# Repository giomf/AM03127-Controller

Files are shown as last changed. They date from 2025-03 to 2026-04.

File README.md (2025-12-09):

# AM03127 LED Panel Controller

This project provides a controller for AM03127 LED panels using an ESP32-C3 microcontroller. It communicates with the panel via RS232 and exposes a REST API through an HTTP server, along with a web interface for easy control.

## Features

- Control AM03127 LED panels via RS232 communication
- Display text with various animations and effects
- Create and manage schedules for automated content display
- Set and display the panel's internal clock
- RESTful API for programmatic control
- Web interface for easy management and OTA updates

## Hardware Requirements

- ESP32-C3 microcontroller
- AM03127 LED panel
- RS232 interface between ESP32-C3 and LED panel

## PCB Design

A custom PCB has been designed for this project. All PCB-related files, including schematics, board layouts, and manufacturing files, can be found in the [PCB](PCB/) folder.

## Software Architecture

The project is built with Rust and uses the following components:

- **Embassy**: Async runtime for embedded systems
- **ESP-HAL**: Hardware abstraction layer for ESP32 devices
- **PicoServe**: Lightweight HTTP server for embedded systems
- **Heapless**: Collections that don't require dynamic memory allocation

## API Documentation

The REST API documentation is available as [OpenAPI Specification](docs/openapi.yaml)

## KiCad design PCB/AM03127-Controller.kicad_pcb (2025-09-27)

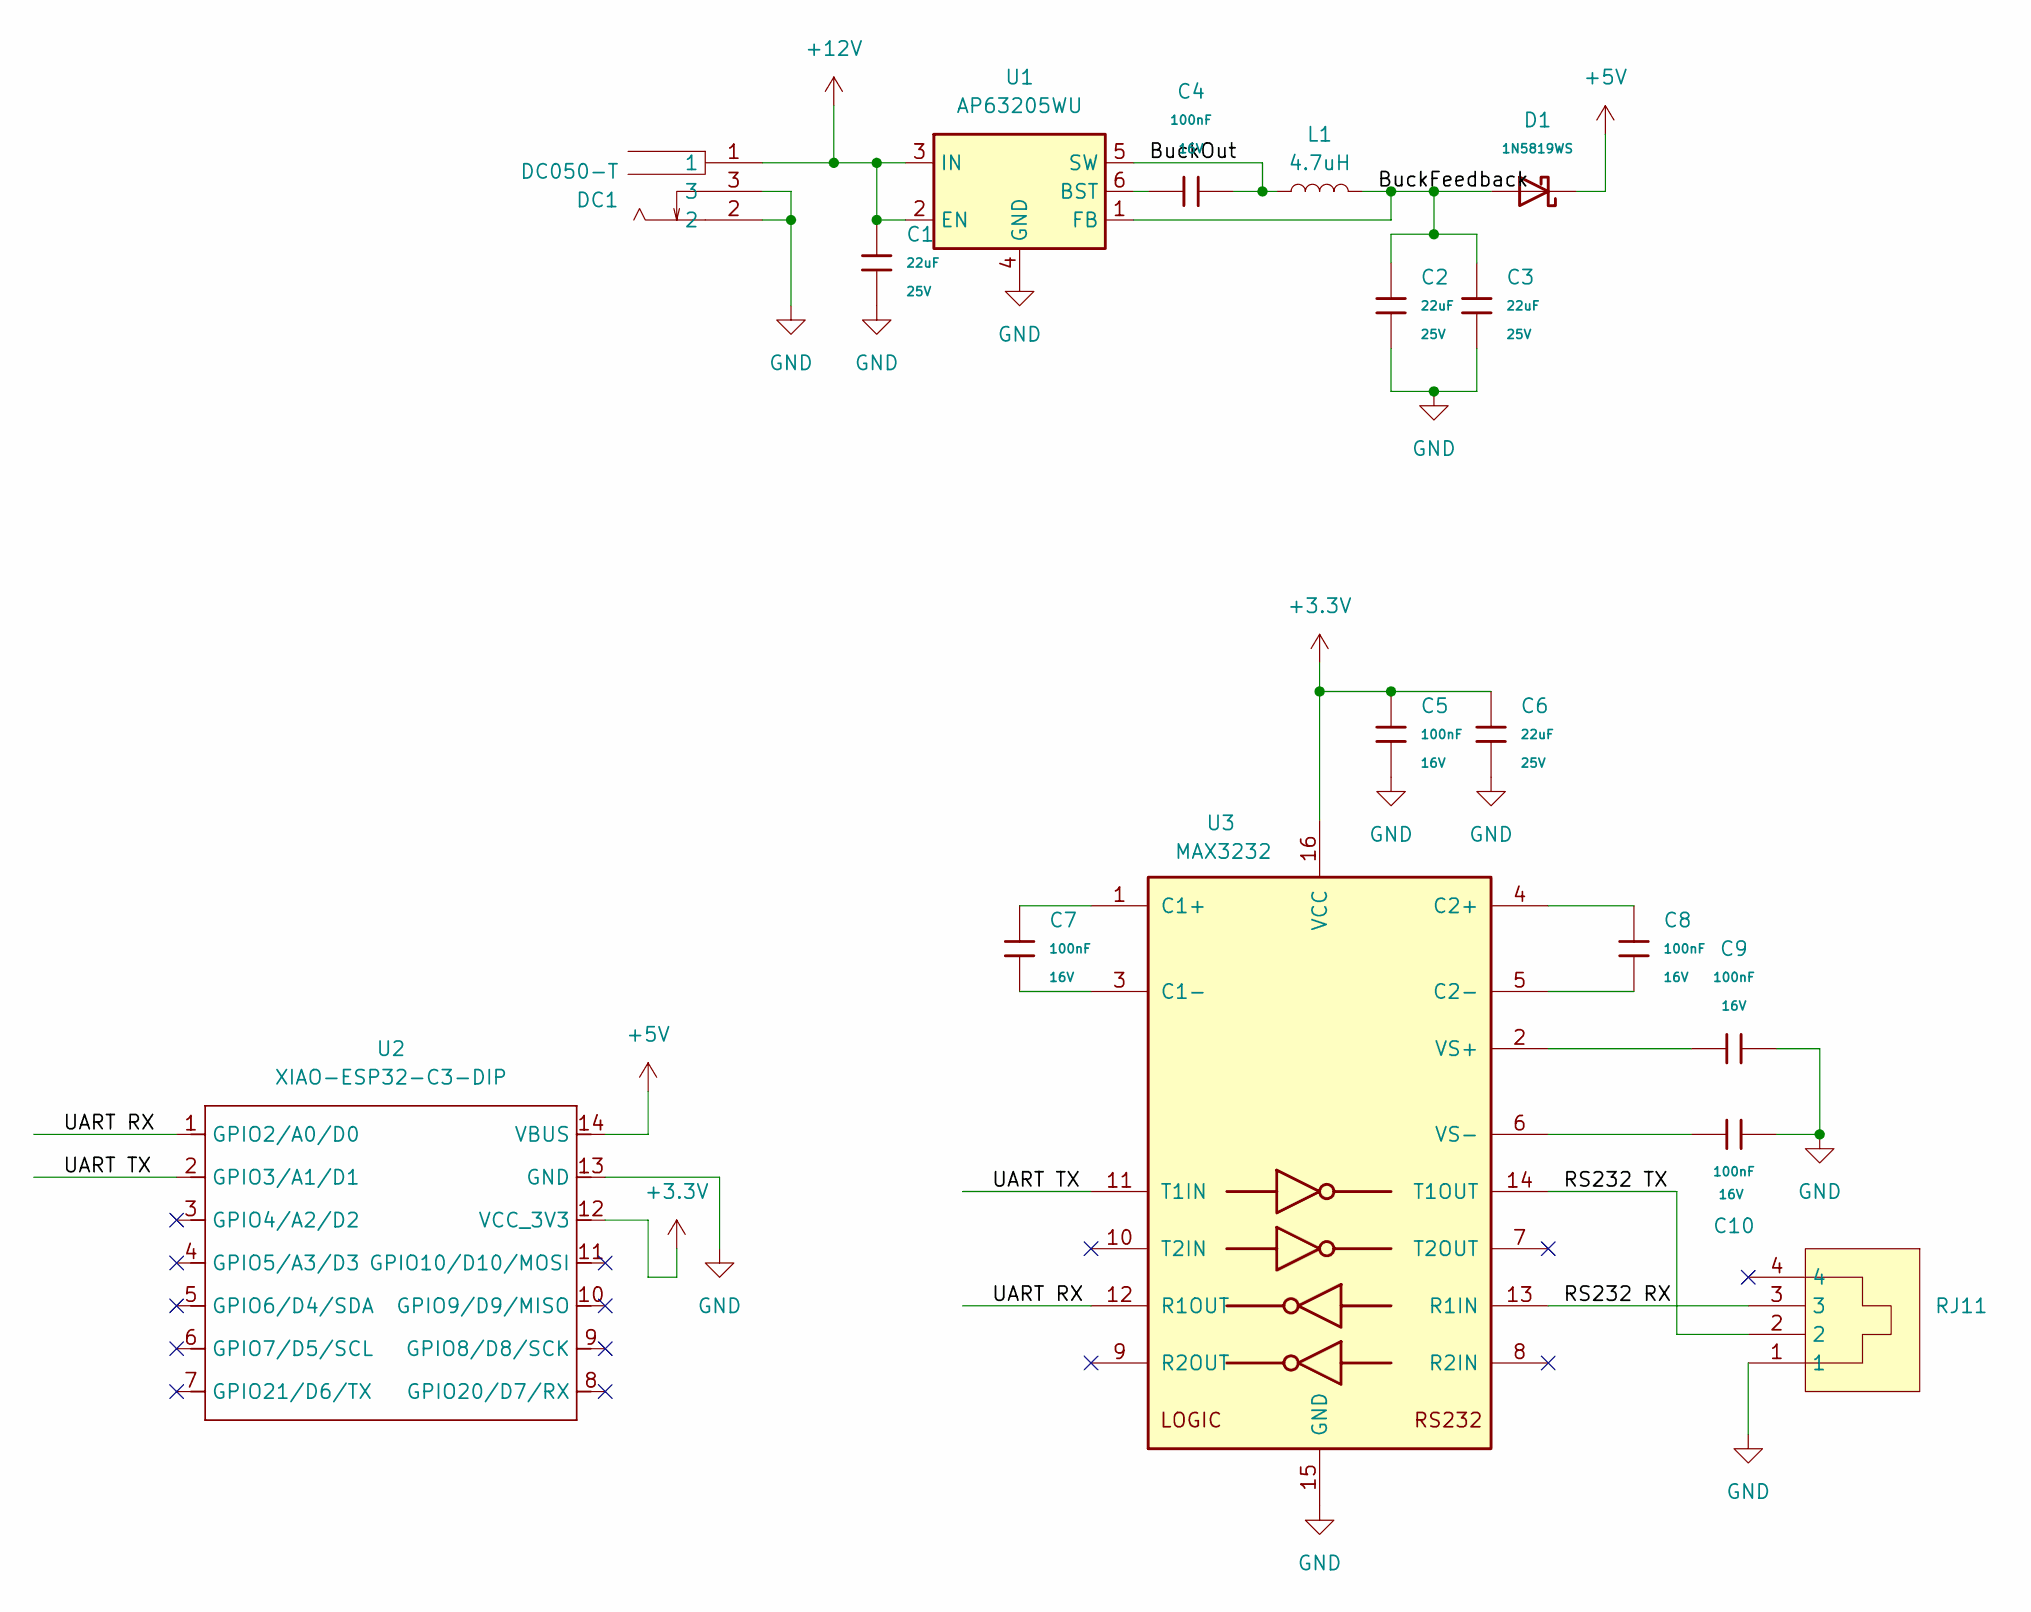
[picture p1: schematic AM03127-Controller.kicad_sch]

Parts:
C1, C2, C3, C6: 22uF; C_1206; Voltage Rated 25V; Tolerance ±10%; Part CL31A226KAHNNNE; LCSC C12891
C4, C5, C7, C8, C9, C10: 100nF; C_0402; Voltage Rated 16V; Tolerance ±10%; Part CL05B104KO5NNNC; LCSC C1525
D1: 1N5819WS; D_SOD-323; Forward Voltage (Vf@If) 600mV@1A; Reverse Voltage (Vr) 40V; Part 1N5819WS; LCSC C191023
DC1: DC050-T; DC-IN_DC050-T; LCSC Part C431534
L1: 4.7uH; L_1008_2520Metric
RJ11: PCB-6P4C-90_C189746; RJ11-TH_PCB-6P4C-90_C189746; LCSC Part C189746
U1: AP63205WU; TSOT-23-6
U2: XIAO-ESP32-C3-DIP; XIAO-ESP32C3-DIP
U3: MAX3232; SOIC-16_3.9x9.9mm_P1.27mm

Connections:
+3.3V: C5.1, C6.1, U2.12 (VCC_3V3), U3.16 (VCC)
+5V: D1.1, U2.14 (VBUS)
+12V: C1.1, DC1.1, U1.2 (EN), U1.3 (IN)
/BuckFeedback: C2.1, C3.1, D1.2, L1.2, U1.1 (FB)
/BuckOut: C4.2, L1.1, U1.5 (SW)
/RS232 RX: RJ11.3, U3.13 (R1IN)
/RS232 TX: RJ11.2, U3.14 (T1OUT)
/UART RX: U2.1 (GPIO2/A0/D0), U3.12 (R1OUT)
/UART TX: U2.2 (GPIO3/A1/D1), U3.11 (T1IN)
GND: C1.2, C2.2, C3.2, C5.2, C6.2, C9.2, C10.2, DC1.2, DC1.3, RJ11.1, U1.4 (GND), U2.13 (GND), U3.15 (GND)
unnamed: C4.1, U1.6 (BST)
unnamed: C7.1, U3.1 (C1+)
unnamed: C7.2, U3.3 (C1-)
unnamed: C8.1, U3.4 (C2+)
unnamed: C8.2, U3.5 (C2-)
unnamed: C9.1, U3.2 (VS+)
unnamed: C10.1, U3.6 (VS-)

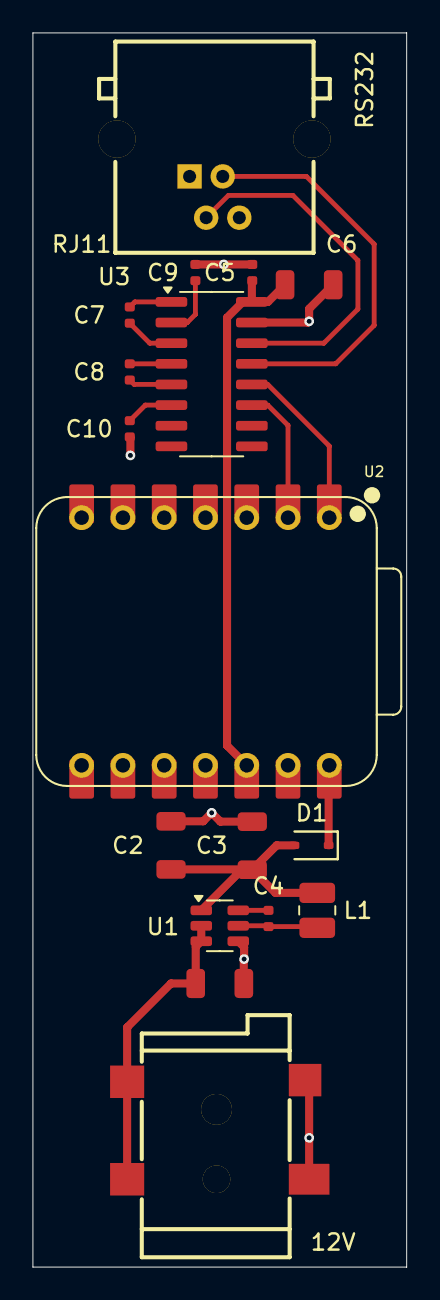
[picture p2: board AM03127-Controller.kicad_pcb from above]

Board: 2 copper layers, 23.0 x 76.0 mm, 17 parts (0 on the bottom side), 17 nets.

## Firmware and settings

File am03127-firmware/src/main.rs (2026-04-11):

#![recursion_limit = "256"]
#![no_std]
#![no_main]
#![feature(impl_trait_in_assoc_type)]
#[deny(clippy::mem_forget)]
#[cfg(feature = "sntp")]
mod clock;
mod error;
mod panel;
mod server;
mod storage;
mod uart;

use embassy_executor::Spawner;
use embassy_net::{Runner, Stack as NetworkStack, StackResources};
use embassy_sync::{blocking_mutex::raw::CriticalSectionRawMutex, mutex::Mutex};
use embassy_time::{Duration, Timer};
use esp_alloc as _;
use esp_backtrace as _;
use esp_bootloader_esp_idf::{esp_app_desc, ota_updater::OtaUpdater};
use esp_hal::{
    clock::CpuClock, interrupt::software::SoftwareInterruptControl, peripherals::WIFI, ram,
    rng::Rng, timer::timg::TimerGroup,
};
use esp_radio::{
    Controller, init,
    wifi::{ClientConfig, ModeConfig, WifiController, WifiDevice, WifiEvent, WifiStaState},
};
use esp_storage::FlashStorage;
use panel::Panel;
use picoserve::{AppRouter, AppWithStateBuilder, Config as ServerConfig, Router, make_static};
use server::{AppState, ServerProperties, web_task};
use uart::Uart;

#[cfg(feature = "sntp")]
use crate::clock::timing_task;

const WEB_TASK_POOL_SIZE: usize = 2;
// Webtask poolsize + sntp socket + one extra
#[cfg(feature = "sntp")]
const STACK_RESSOURCE_SIZE: usize = WEB_TASK_POOL_SIZE + 1 + 1;
// Webtask poolsize + one extra
#[cfg(not(feature = "sntp"))]
const STACK_RESSOURCE_SIZE: usize = WEB_TASK_POOL_SIZE + 1;
const SSID: &str = env!("WIFI_SSID");
const PASSWORD: &str = env!("WIFI_PASS");
const PANEL_INIT_DELAY_SECS: u64 = 10;
const WIFI_DELAY_SECS: u64 = 5;

pub type SharedUart = &'static Mutex<CriticalSectionRawMutex, Uart<'static>>;
pub type SharedStorage = &'static Mutex<CriticalSectionRawMutex, FlashStorage<'static>>;

esp_app_desc!(
    env!("BUILD_VERSION"), // version
    "AM03127-Controller",  // project name
    env!("BUILD_TIME"),    // build time
    env!("BUILD_DATE"),    // build date
    "5.2",                 // ESP-IDF version
    64 * 1024,             // MMU page size
    0,                     // min eFuse block revision
    u16::MAX               // max eFuse block revision
);

#[esp_rtos::main]
async fn main(spawner: Spawner) {
    esp_println::logger::init_logger_from_env();
    let esp_config = esp_hal::Config::default().with_cpu_clock(CpuClock::max());
    let peripherals = esp_hal::init(esp_config);

    // 100 KB Heap
    esp_alloc::heap_allocator!(#[ram(reclaimed)] size: 64 * 1024);
    esp_alloc::heap_allocator!(size: 36 * 1024);

    let timg0 = TimerGroup::new(peripherals.TIMG0);
    let shared_uart = make_static!(
        Mutex<CriticalSectionRawMutex, Uart>, Mutex::new(Uart::new(peripherals.UART1, peripherals.GPIO3, peripherals.GPIO2))
    );
    let shared_storage = make_static!(Mutex<CriticalSectionRawMutex, FlashStorage>, Mutex::new(FlashStorage::new(peripherals.FLASH)));
    let panel = make_static!(Panel, Panel::new(shared_uart, shared_storage));

    let mut ota_buffer = [0u8; esp_bootloader_esp_idf::partitions::PARTITION_TABLE_MAX_LEN];
    let (selected_partition, booted_partition) = {
        let flash = &mut *shared_storage.lock().await;
        let mut pt_buffer = [0u8; esp_bootloader_esp_idf::partitions::PARTITION_TABLE_MAX_LEN];
        let pt = esp_bootloader_esp_idf::partitions::read_partition_table(flash, &mut pt_buffer)
            .unwrap();
        let booted = pt
            .booted_partition()
            .ok()
            .flatten()
            .map(|p| p.partition_type());
        let mut ota = OtaUpdater::new(flash, &mut ota_buffer).unwrap();
        let selected = ota.selected_partition().unwrap();
        (selected, booted)
    };

    log::info!("==========================================");
    log::info!("\tAM03127-Controller");
    log::info!("\tVersion:\t\t{}", env!("BUILD_VERSION"));
    log::info!(
        "\tBuilt:\t\t\t{} {}",
        env!("BUILD_DATE"),
        env!("BUILD_TIME")
    );
    match booted_partition {
        Some(p) => log::info!("\tBooted partition:\t{:?}", p),
        None => log::info!("\tBooted partition:\tUnknown"),
    }
    log::info!("\tSelected partition:\t{:?}", selected_partition);
    log::info!("==========================================");

    #[cfg(target_arch = "riscv32")]
    let sw_int = SoftwareInterruptControl::new(peripherals.SW_INTERRUPT);
    esp_rtos::start(
        timg0.timer0,
        #[cfg(target_arch = "riscv32")]
        sw_int.software_interrupt0,
    );

    let (wifi_controller, wifi_interface) = init_wifi(peripherals.WIFI);
    let (network_stack, network_runner) = init_network(wifi_interface);
    let (server_app, server_config) = init_server();

    spawner.must_spawn(wifi_task(wifi_controller, network_stack));
    spawner.must_spawn(network_task(network_runner));
    spawner.must_spawn(panel_init_task(panel));
    #[cfg(feature = "sntp")]
    spawner.must_spawn(timing_task(network_stack, panel));

    for id in 0..WEB_TASK_POOL_SIZE {
        spawner.must_spawn(web_task(
            id,
            network_stack,
            server_app,
            server_config,
            AppState {
                panel: panel,
                storage: shared_storage,
            },
        ));
    }
}

fn init_wifi(wifi: WIFI<'static>) -> (WifiController<'static>, WifiDevice<'static>) {
    let esp_radio_ctrl = &*make_static!(Controller<'static>, init().unwrap());
    let (controller, interfaces) =
        esp_radio::wifi::new(&esp_radio_ctrl, wifi, Default::default()).unwrap();
    let device = interfaces.sta;

    return (controller, device);
}

fn init_network(
    wifi_device: WifiDevice<'static>,
) -> (NetworkStack<'static>, Runner<'static, WifiDevice<'static>>) {
    let rng = Rng::new();
    let config = embassy_net::Config::dhcpv4(Default::default());
    let seed = (rng.random() as u64) << 32 | rng.random() as u64;

    // Init network stack
    embassy_net::new(
        wifi_device,
        config,
        make_static!(StackResources<STACK_RESSOURCE_SIZE>, StackResources::new()),
        seed,
    )
}

fn init_server() -> (
    &'static mut Router<<ServerProperties as AppWithStateBuilder>::PathRouter, AppState>,
    &'static mut ServerConfig,
) {
    let server_app = make_static!(AppRouter<ServerProperties>, ServerProperties.build_app());
    let server_config = make_static!(
        ServerConfig,
        ServerConfig::new(picoserve::Timeouts {
            persistent_start_read_request: Duration::from_secs(5),
            start_read_request: Duration::from_secs(5),
            read_request: Duration::from_secs(60),
            write: Duration::from_secs(2),
        })
        .keep_connection_alive()
    );

    (server_app, server_config)
}

#[embassy_executor::task]
async fn wifi_task(
    mut wifi_controller: WifiController<'static>,
    network_stack: NetworkStack<'static>,
) {
    const LOGGER_NAME: &str = "WIFI";
    log::info!("{LOGGER_NAME}: Start wifi connection task");

    loop {
        if matches!(esp_radio::wifi::sta_state(), WifiStaState::Connected) {
            // wait until we're no longer connected
            wifi_controller
                .wait_for_event(WifiEvent::StaDisconnected)
                .await;
            log::info!("{LOGGER_NAME}: Wifi disconnected");
            Timer::after(Duration::from_secs(WIFI_DELAY_SECS)).await
        }
        if !matches!(wifi_controller.is_started(), Ok(true)) {
            let client_config = ModeConfig::Client(
                ClientConfig::default()
                    .with_ssid(SSID.try_into().unwrap())
                    .with_password(PASSWORD.try_into().unwrap()),
            );
            wifi_controller.set_config(&client_config).unwrap();
            log::info!("{LOGGER_NAME}: Starting wifi");
            wifi_controller.start_async().await.unwrap();
            log::info!("{LOGGER_NAME}: Wifi started");
        }

        match wifi_controller.connect_async().await {
            Ok(_) => {
                log::info!("{LOGGER_NAME}: Wifi connected to {SSID}");
                network_stack.wait_link_up().await;
                log::info!("{LOGGER_NAME}: Getting DHCP IP address");
                network_stack.wait_config_up().await;

                match network_stack.config_v4() {
                    Some(config) => {
                        log::info!("{LOGGER_NAME}: Received DHCP IP address {}", config.address)
                    }
                    None => log::error!("{LOGGER_NAME}: Failed to receive DHCP IP address"),
                }
            }
            Err(e) => {
                log::info!(
                    "{LOGGER_NAME}: Failed to connect to wifi \"{SSID}\": {:?}",
                    e
                );
                Timer::after(Duration::from_secs(WIFI_DELAY_SECS)).await
            }
        }
    }
}

#[embassy_executor::task]
async fn network_task(mut runner: Runner<'static, WifiDevice<'static>>) -> ! {
    const LOGGER_NAME: &str = "Network";
    log::info!("{LOGGER_NAME}: Start network task");
    runner.run().await
}

#[embassy_executor::task]
async fn panel_init_task(panel: &'static Panel) {
    Timer::after(Duration::from_secs(PANEL_INIT_DELAY_SECS)).await;

    match panel.init().await {
        Ok(_) => log::info!("Panel initialized"),
        Err(e) => log::error!("Failed to initialize panel. {e}"),
    }
}

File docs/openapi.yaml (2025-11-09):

openapi: 3.0.3
info:
  title: LED Panel Control API
  description: API for controlling AM03127 LED panels
  version: 1.0.0
servers:
  - url: http://localhost:80
    description: Local development server
paths:
  /page/{pageId}:
    parameters:
      - name: pageId
        in: path
        required: true
        schema:
          type: string
          pattern: '^[A-Z]$'
        description: Single uppercase letter (A-Z) identifying the page
    get:
      summary: Get a specific page
      description: Retrieves the content and settings of a specific page by ID
      responses:
        '200':
          description: Page found and returned
          content:
            application/json:
              schema:
                $ref: '#/components/schemas/Page'
        '400':
          description: Invalid page ID
          content:
            text/plain:
              schema:
                type: string
        '404':
          description: Page not found
          content:
            text/plain:
              schema:
                type: string
        '500':
          description: Internal server error
          content:
            text/plain:
              schema:
                type: string
    post:
      summary: Create or update a page
      description: Creates a new page or updates an existing page with the specified ID
      requestBody:
        required: true
        content:
          application/json:
            schema:
              $ref: '#/components/schemas/Page'
      responses:
        '200':
          description: Page created or updated successfully
        '400':
          description: Invalid page ID or request body
          content:
            text/plain:
              schema:
                type: string
        '500':
          description: Internal server error
          content:
            text/plain:
              schema:
                type: string
    delete:
      summary: Delete a page
      description: Deletes a page with the specified ID
      responses:
        '200':
          description: Page deleted successfully
        '400':
          description: Invalid page ID
          content:
            text/plain:
              schema:
                type: string
        '500':
          description: Internal server error
          content:
            text/plain:
              schema:
                type: string
  /pages:
    get:
      summary: Get all pages
      description: Retrieves all stored pages
      responses:
        '200':
          description: List of pages
          content:
            application/json:
              schema:
                type: array
                items:
                  $ref: '#/components/schemas/Page'
        '500':
          description: Internal server error
          content:
            text/plain:
              schema:
                type: string
    post:
      summary: Create or update multiple pages
      description: Creates or updates multiple pages at once
      requestBody:
        required: true
        content:
          application/json:
            schema:
              type: array
              items:
                $ref: '#/components/schemas/Page'
      responses:
        '200':
          description: Pages created or updated successfully
        '400':
          description: Invalid request body
          content:
            text/plain:
              schema:
                type: string
        '500':
          description: Internal server error
          content:
            text/plain:
              schema:
                type: string
  /schedule/{scheduleId}:
    parameters:
      - name: scheduleId
        in: path
        required: true
        schema:
          type: string
          pattern: '^[A-E]$'
        description: Single uppercase letter (A-E) identifying the schedule
    get:
      summary: Get a specific schedule
      description: Retrieves a specific schedule by ID
      responses:
        '200':
          description: Schedule found and returned
          content:
            application/json:
              schema:
                $ref: '#/components/schemas/Schedule'
        '400':
          description: Invalid schedule ID
          content:
            text/plain:
              schema:
                type: string
        '404':
          description: Schedule not found
          content:
            text/plain:
              schema:
                type: string
        '500':
          description: Internal server error
          content:
            text/plain:
              schema:
                type: string
    post:
      summary: Create or update a schedule
      description: Creates a new schedule or updates an existing schedule with the specified ID
      requestBody:
        required: true
        content:
          application/json:
            schema:
              $ref: '#/components/schemas/Schedule'
      responses:
        '200':
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

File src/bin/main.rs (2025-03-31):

#![no_std]
#![no_main]

use embassy_executor::Spawner;
use embassy_net::{Runner,  StackResources};
use embassy_time::{Duration, Timer};
use esp_alloc as _;
use esp_hal::timer::systimer::SystemTimer;
use esp_hal::{clock::CpuClock, rng::Rng, timer::timg::TimerGroup};
use esp_backtrace as _;
use esp_println::println;
use esp_wifi::{
    EspWifiController, init,
    wifi::{ClientConfiguration, Configuration, WifiController, WifiDevice, WifiEvent, WifiState},
};

// When you are okay with using a nightly compiler it's better to use https://docs.rs/static_cell/2.1.0/static_cell/macro.make_static.html
macro_rules! mk_static {
    ($t:ty,$val:expr) => {{
        static STATIC_CELL: static_cell::StaticCell<$t> = static_cell::StaticCell::new();
        #[deny(unused_attributes)]
        let x = STATIC_CELL.uninit().write(($val));
        x
    }};
}

extern crate alloc;

const SSID: &str = env!("WIFI_SSID");
const PASSWORD: &str = env!("WIFI_PASS");


#[esp_hal_embassy::main]
async fn main(spawner: Spawner) {
    esp_println::logger::init_logger_from_env();
    let config = esp_hal::Config::default().with_cpu_clock(CpuClock::max());
    let peripherals = esp_hal::init(config);

    esp_alloc::heap_allocator!(size: 72 * 1024);

    let timg0 = TimerGroup::new(peripherals.TIMG0);
    let mut rng = Rng::new(peripherals.RNG);

    let esp_wifi_ctrl = &*mk_static!(
        EspWifiController<'static>,
        init(timg0.timer0, rng.clone(), peripherals.RADIO_CLK).unwrap()
    );

    let (wifi_controller, interfaces) =
        esp_wifi::wifi::new(&esp_wifi_ctrl, peripherals.WIFI).unwrap();
    let wifi_interface = interfaces.sta;

    let systimer = SystemTimer::new(peripherals.SYSTIMER);
    esp_hal_embassy::init(systimer.alarm0);

    let config = embassy_net::Config::dhcpv4(Default::default());
    let seed = (rng.random() as u64) << 32 | rng.random() as u64;

    // Init network stack
    let (network_stack, network_runner) = embassy_net::new(
        wifi_interface,
        config,
        mk_static!(StackResources<3>, StackResources::<3>::new()),
        seed,
    );

    spawner.spawn(net_task(network_runner)).ok();
    spawner.spawn(wifi_connection(wifi_controller)).ok();

    network_stack.wait_link_up().await;
    network_stack.wait_config_up().await;

    match network_stack.config_v4() {
        Some(config) => println!("DHCP IP: {}", config.address),
        None => println!("Failed to receive DHCP IP address"),
    }
}

#[embassy_executor::task]
async fn wifi_connection(mut wifi_controller: WifiController<'static>) {
    println!("Start wifi connection task");
    loop {
        match esp_wifi::wifi::wifi_state() {
            WifiState::StaConnected => {
                // wait until we're no longer connected
                wifi_controller
                    .wait_for_event(WifiEvent::StaDisconnected)
                    .await;
                Timer::after(Duration::from_millis(5000)).await
            }
            _ => {}
        }
        if !matches!(wifi_controller.is_started(), Ok(true)) {
            let client_config = Configuration::Client(ClientConfiguration {
                ssid: SSID.try_into().unwrap(),
                password: PASSWORD.try_into().unwrap(),
                ..Default::default()
            });
            wifi_controller.set_configuration(&client_config).unwrap();
            println!("Starting wifi");
            wifi_controller.start_async().await.unwrap();
            println!("Wifi started!");
        }
        println!("About to connect to wifi...");

        match wifi_controller.connect_async().await {
            Ok(_) => println!("Wifi connected!"),
            Err(e) => {
                println!("Failed to connect to wifi: {:?}", e);
                Timer::after(Duration::from_millis(5000)).await
            }
        }
    }
}

#[embassy_executor::task]
async fn net_task(mut runner: Runner<'static, WifiDevice<'static>>) {
    runner.run().await
}

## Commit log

2025-04-03 add uart
2025-04-13 Add uart write method
2025-04-19 Init kicad project
    [Seeed_Studio_XIAO_RP2040_v26.step, ff-led-panel.kicad_pcb, ff-led-panel.kicad_sch]
2025-04-24 Add storage
    [partition-table.csv]
2025-05-05 Add custom error type
    [error.rs, main.rs, panel.rs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]
2025-05-05 Remove println
2025-05-14 Add reset endpoint
    [partition-table.csv]
2025-05-14 Do not fail when uart gives negative response
    [uart.rs]
2025-08-29 Create gerbe files for pcb
    [ff-led-panel-CuBottom.gbr, ff-led-panel-CuTop.gbr, ff-led-panel-EdgeCuts.gbr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]
2025-08-29 Restructure PCB project
    [AM03127-Controller-CuBottom.gbr, AM03127-Controller-CuTop.gbr, AM03127-Controller-EdgeCuts.gbr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]
2025-08-29 Refactor PCB to use global label nets
    [AM03127-Controller.kicad_pcb, AM03127-Controller.kicad_sch]
2025-09-07 Refactor LDO to Buckconverter
    [AM03127-Controller-CuBottom.gbr, AM03127-Controller-CuTop.gbr, AM03127-Controller-EdgeCuts.gbr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]
2025-09-07 Change Uart RX/TX
2025-09-11 Refactor PCB using buttom GND Plate
    [AM03127-Controller-CuBottom.gbr, AM03127-Controller-CuTop.gbr, AM03127-Controller-EdgeCuts.gbr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]
2025-09-27 Fix swaped pin for voltage regulator in PCB
    [AM03127-Controller-CuBottom.gbr, AM03127-Controller-CuTop.gbr, AM03127-Controller-EdgeCuts.gbr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]
2025-10-28 Reconnect on wifi interrupts
2025-10-28 Initialize Panel on a seperate Task and allow it to fail
    [main.rs]
2025-10-28 Use timeouts for uart read and write
2025-10-28 Replace SharedPanel tuple struct with type alias
    [clock.rs, main.rs]
2025-10-30 Add OTA
    [partition-table.csv]
2025-11-12 Print current booted partition when starting
2026-04-01 fix: increase read request time for ota
    [main.rs]
2026-04-01 fix: recreate UDP socket for timing task every iteration
    [clock.rs]
2026-04-01 feat: Add automatic date time saving switch for eu
2026-04-05 feat(cli): Add error handling via anyhow
    [main.rs, status.rs]
2026-04-05 feat(cli): use indicatif to print progress bars
2026-04-09 chore: Split up workspaces to allow multi target builds
    [partition-table.csv]
2026-04-09 feat(cli): Print status information from /status endpoint
2026-04-09 feat(cli): print firmware infos before updating
2026-04-10 fix(cli): use config only where its needed
    [main.rs]
2026-04-11 feat(ctrl): Print SSID in use
2026-04-11 refactor(cli): Cut out am03127-client to allow future backend implementation to use the same lib
2026-04-11 feat(all): Rename workspace members
    [partition-table.csv]
2026-04-11 chore(firmware): Remove unused partition-table
    [partition-table.csv]
2026-06-03 feat: Add systemd timer to push clock every 12h
2026-11-05 fix(firmware): reject page/schedule whose path and body ID differ
    The panel got the body's ID while flash stored it under the path's ID,
    so after a reboot the wrong slot was restored.
2026-11-05 fix(firmware): reconnect wifi when DHCP does not complete
    A disconnect between connecting and getting an IP left the wifi task
    waiting forever and the device never reconnected.
2026-11-05 fix(firmware): keep UART locked until flash is written
    Two concurrent saves of the same ID could leave the panel with one
    version and flash with the other.
2026-11-05 fix(firmware): derive storage addresses from partition table
    build.rs splits the nvs partition of partition-table.csv into page and
    schedule storage instead of hard-coding the addresses. The layout for
    the current table is unchanged.
2026-11-05 feat: add red color to delete button
2026-11-05 chore(webui): redesing device page
